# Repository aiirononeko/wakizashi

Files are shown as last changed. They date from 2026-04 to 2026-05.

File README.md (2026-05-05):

# Wakizashi

極限までミニマルな36キーBLE無線キーボード（revB）。メインキーボードとは別に、常に携えるサブキーボードとして設計。

- **キー数**: 36（3行×12列、論理 6×6 マトリクスに折り畳み）
- **配列**: オーソリニア（格子配列）
- **キーピッチ**: 16mm
- **接続**: BLE無線（USB-Cは充電とファーム書き込み用）
- **MCU**: XIAO nRF52840
- **キースイッチ**: Kailh Choc V2（ホットスワップ対応）
- **電源**: LiPoバッテリー（PicoBlade 1.25mm 2ピン）
- **電池監視**: VBAT 分圧 (R2 2.2MΩ + R3 1MΩ) → P0.31 (AIN7)、BLE HID Battery Service でホスト通知
- **ステータス LED**: SK6812MINI × 1（裏面右奥、SPIM3 駆動）。BLE 接続=青常時、ペアリング待機=青点滅、USB 接続=白、電池低下=赤、緊急=赤点滅、充電中=黄点滅、アイドル時は AO3401A PMOS で VDD ごと遮断
- **ファームウェア**: [RMK](https://github.com/HaoboGu/rmk)（Rust）
- **ケース**: revB ケース一式（topplate / side / spacer / bottomplate、3MF と STEP を収録）

## リポジトリ構成

```
wakizashi/
├── firmware/           RMK ファームウェア（nRF52840）
├── case/               ケース出力データ（3MF / STEP）
├── tools/web-flasher/  ブラウザから書き込む Web Flasher
├── build-guide/        組み立てガイド
└── docs/               運用ドキュメント
```

## ドキュメント

- [組み立てガイド](./build-guide/) — 必要部品 / 組み立て手順
- [ファームウェアの書き込み](./docs/flashing.md) — Web Flasher / UF2 / ローカルビルド
- [リリース運用](./docs/releasing.md) — タグ付け / CI / Pages デプロイ

## ファームウェアの書き込み (概要)

ブラウザから 1 クリックで書き込める [Web Flasher](https://e-sp9.github.io/wakizashi/) を公開している。USB-C でつなげば、自動でブートローダに入り最新ファームを書き込む。詳細と代替手順は [docs/flashing.md](./docs/flashing.md) を参照。

## キーマップ

詳細仕様は [firmware/keyboard.toml](./firmware/keyboard.toml) を参照。ホームロウモッドは廃止し、左右外側の Tab/Ctrl/Shift・BS/Enter/MO2 を直接キー化。コンボ（Q+W=Esc / F+V=Space / J+M=Space / Z+X=LGui / F+D=英数 / J+K=かな）と 3 レイヤー構成（base / lower / raise）。`MO(1)` を押しながら右上端（Backspace 位置）で `Minus` を入力できる。RMK そのものは [RMK ドキュメント](https://rmk.rs/main/docs/) を参照。

## ライセンス

MIT License — 詳細は [LICENSE](./LICENSE) を参照。

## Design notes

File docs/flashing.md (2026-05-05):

# ファームウェアの書き込み

書き込み方法は 3 通り。いずれも USB-C ケーブル (データ通信対応) での PC 接続が必要。

## 1. Web Flasher (推奨)

ブラウザだけで最新ファームを書き込める。Chrome / Edge / Opera の最新版に対応。

👉 **[https://e-sp9.github.io/wakizashi/](https://e-sp9.github.io/wakizashi/)**

1. 「最新ファームを取得」— GitHub Releases から最新 DFU パッケージを同一オリジンで読み込む
2. 「キーボードを選択して再起動」— WebHID でキーボードを選ぶと、Vial の `BootloaderJump` コマンドで自動的にブートローダへ再起動
3. 「シリアルポートを選んで書き込み」— WebSerial でブートローダの CDC ポートを選ぶと、Nordic Legacy DFU で書き込みが始まる

ブラウザと仕組みの詳細は [tools/web-flasher/](../tools/web-flasher/) のソースを参照。

## 2. UF2 ドラッグ & ドロップ

Web Flasher が使えない環境でのフォールバック。

1. キーボードのリセットボタンを素早く 2 回押してブートローダモードに入る (PC 上に `XIAO-SENSE` などの USB ドライブが出現)
2. [Releases](https://github.com/e-sp9/wakizashi/releases/latest) から `wakizashi.uf2` をダウンロード
3. ダウンロードした `.uf2` をドライブにコピー — 自動的に書き込まれて再起動する

## 3. ローカルビルドから書き込み

ファームを改造したとき用。

### 環境セットアップ

- Rust toolchain (`rust-toolchain.toml` で固定)
- [`cargo-make`](https://github.com/sagiegurari/cargo-make)
- `cargo-binutils`, [`cargo-hex-to-uf2`](https://github.com/haobogu/cargo-hex-to-uf2) (Makefile.toml の中でインストール / 呼び出し)
- 任意: `adafruit-nrfutil` (`pip install adafruit-nrfutil`)

### UF2 を生成してドラッグ & ドロップ

```sh
cd firmware
cargo make uf2
# 生成された firmware/wakizashi.uf2 を UF2 と同じ手順でドライブにコピー
```

### adafruit-nrfutil で CDC DFU 書き込み

```sh
cd firmware
cargo make hex
adafruit-nrfutil dfu genpkg --dev-type 0x0052 --application wakizashi.hex wakizashi-dfu.zip
# Linux/macOS 例。Windows は COMn を指定
adafruit-nrfutil dfu serial --package wakizashi-dfu.zip -p /dev/ttyACM0 -b 115200
```

## トラブルシュート

| 症状 | 対処 |
|---|---|
| PC に USB デバイスとして見えない | ケーブルがデータ通信対応か確認 (充電専用ケーブルでは不可) |
| ブートローダに入れない | XIAO 本体のリセットボタンを **素早く 2 回** 押す（revB は外付けリセットスイッチを撤廃、ケース開口から XIAO 内蔵ボタンを直接押す）。LED が流れるように点滅したらブートローダ |
| Web Flasher の「シリアルポート選択」ダイアログに候補が出ない | キーボードがブートローダモードになっていない。手動で 2 回リセット |
| 書き込み後にキーボードが動かない | 再びブートローダに入り、[過去のリリース](https://github.com/e-sp9/wakizashi/releases) の `wakizashi.uf2` で復旧できる |
| Web Flasher の書き込みが `START_DFU` で止まる | ブラウザをハードリロード → 別のケーブル / ポートで再試行 |

詳細なログを追うときは、Web Flasher を開いて DevTools → Console を見る。`[dfu]` プレフィックスで TX/RX バイトが出力される。

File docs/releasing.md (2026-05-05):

# リリース運用

Wakizashi のファームウェアリリースは `main` への `firmware/` 変更マージを起点に自動化されている。手動で操作が必要になるのはメジャー / マイナーバージョンを上げるときだけ。

## 自動化フロー

```
firmware/ の変更が main にマージ
    │
    ▼  .github/workflows/auto-tag.yml
直近の v* タグから patch を +1 して新しいタグを push
    │
    ▼  .github/workflows/firmware.yml  (on push tags: 'v*')
UF2 / HEX / DFU zip をビルドして GitHub Release を作成
    │
    ▼  .github/workflows/pages.yml  (on release: published)
最新ファームを Web Flasher に同梱して GitHub Pages を再デプロイ
```

`firmware/` に触れない変更 (`tools/`, `case/`, `docs/`, `README.md` 等) は auto-tag の対象外なので、何度マージしてもタグは増えない。

## 日常のリリース: 何もしない

`firmware/` を変更した PR を `main` にマージするだけでよい。上記のフローがすべて走り、数分後には最新ビルドが [Web Flasher](https://e-sp9.github.io/wakizashi/) と [Releases](https://github.com/e-sp9/wakizashi/releases/latest) の両方で配布される。

## メジャー / マイナーを上げる: 手動

セマンティックバージョニングの意図を明示するため、patch 以外のバンプは手動で切る。

```sh
# 例: 破壊的変更で v1.0.0 に上げる
git tag v1.0.0
git push origin v1.0.0
```

タグ push 後は `firmware.yml` と `pages.yml` が自動で走って Release と Pages が更新される。

### auto-tag より先に手動でタグを切ってしまった場合

auto-tag は「HEAD にすでにタグがあれば skip」する判定を入れてあるので、手動タグの後に `firmware/` 変更を含む push が来ても重ねてタグは切られない。

### auto-tag が先に patch を切ってしまった場合

タグは同一コミットに複数付けられる。意図より小さなバンプが先に切られた場合、そのまま意図したバンプのタグを重ねて切れば、新しい Release はそちらで公開される (Release 本体は最新タグに紐づく)。必要であれば古いタグ / Release を削除して整理する。

## 手動実行

Actions タブから各 workflow を `Run workflow` で個別に動かせる。

- **Auto-tag firmware release** — `bump` (patch/minor/major) を選んで手動タグ付けできる。
- **Build firmware** — `workflow_dispatch` でビルド単体 (Release 添付は v* タグ push 時のみ)。
- **Deploy web flasher** — ファームを更新せず Pages だけ再デプロイ。

## ワークフローの責任範囲

| Workflow | トリガ | 仕事 |
|---|---|---|
| `auto-tag.yml` | `push` to main (firmware/ 変更時) / 手動 | 次のタグを決めて push するだけ |
| `firmware.yml` | 全 push / PR / `v*` タグ / 手動 | ビルド + アーティファクト保存。タグ push 時は Release 添付 |
| `pages.yml` | `push` to main (tools/web-flasher/ 変更時) / `release: published` / 手動 | Web Flasher + 最新ファームを Pages にデプロイ |

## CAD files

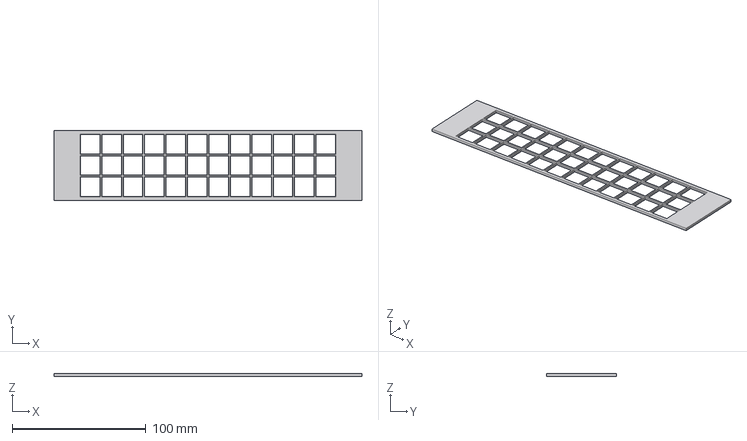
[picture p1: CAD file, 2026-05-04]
case/wakizashi_case.step
230.0 x 52.0 x 2.00 mm

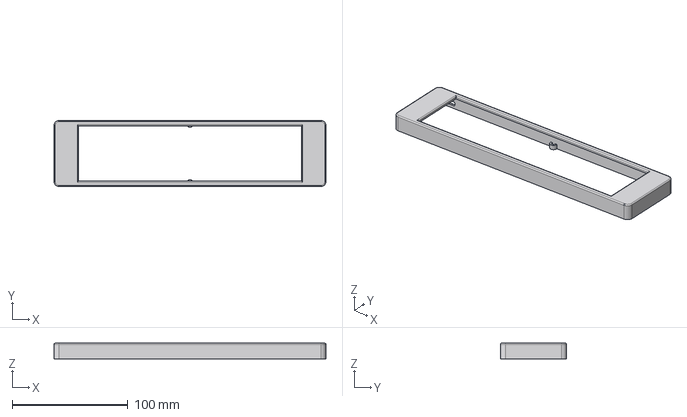
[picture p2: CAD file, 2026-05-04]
case/wakizashi_side.step
235.3 x 57.3 x 13.5 mm

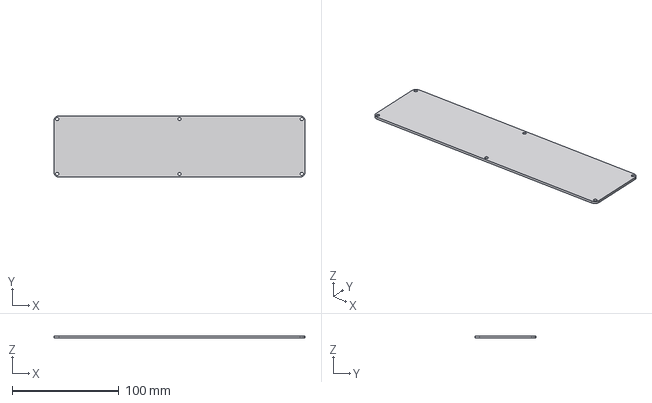
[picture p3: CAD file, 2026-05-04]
case/wakizashi_bottomplate.step
235.3 x 57.3 x 2.00 mm

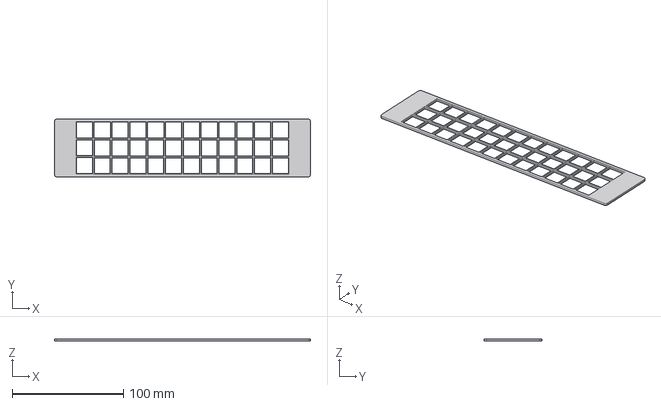
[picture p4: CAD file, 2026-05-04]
case/wakizashi_topplate.step
230.0 x 52.0 x 2.00 mm

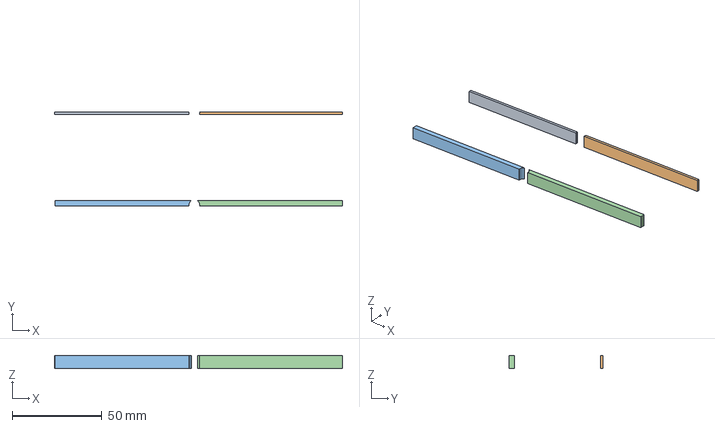
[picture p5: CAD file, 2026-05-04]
case/wakizashi_spacer.step
160.1 x 52.3 x 7.00 mm

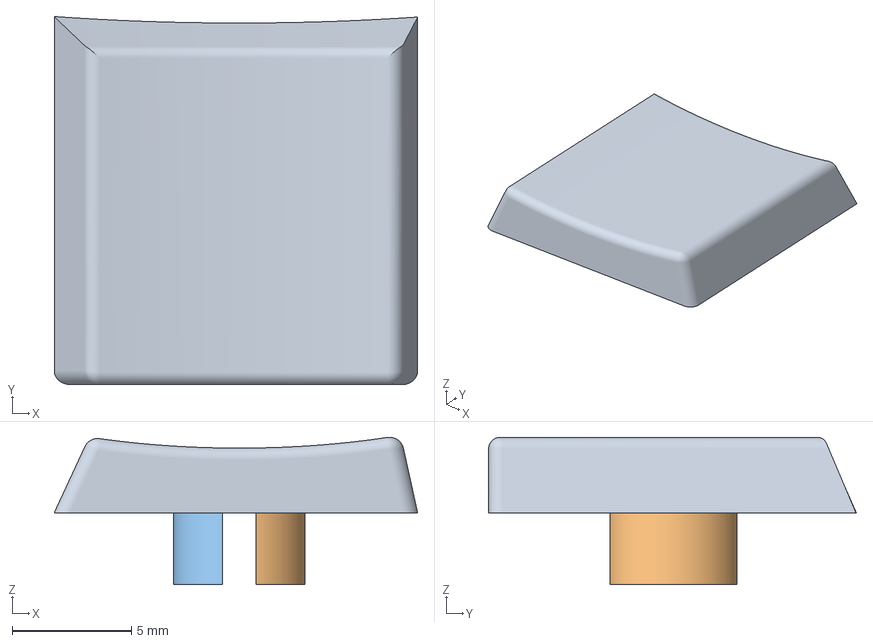
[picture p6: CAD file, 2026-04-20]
case/keycap_bottom.3mf
15.2 x 15.4 x 6.17 mm

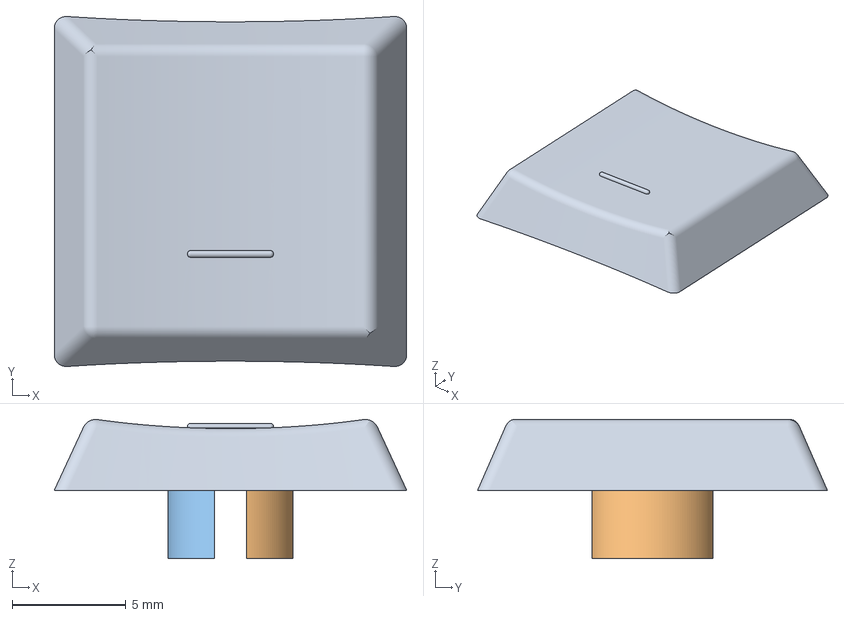
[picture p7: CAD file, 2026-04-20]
case/keycap_middle_dot.3mf
15.5 x 15.4 x 6.12 mm
keycap_middle_dot

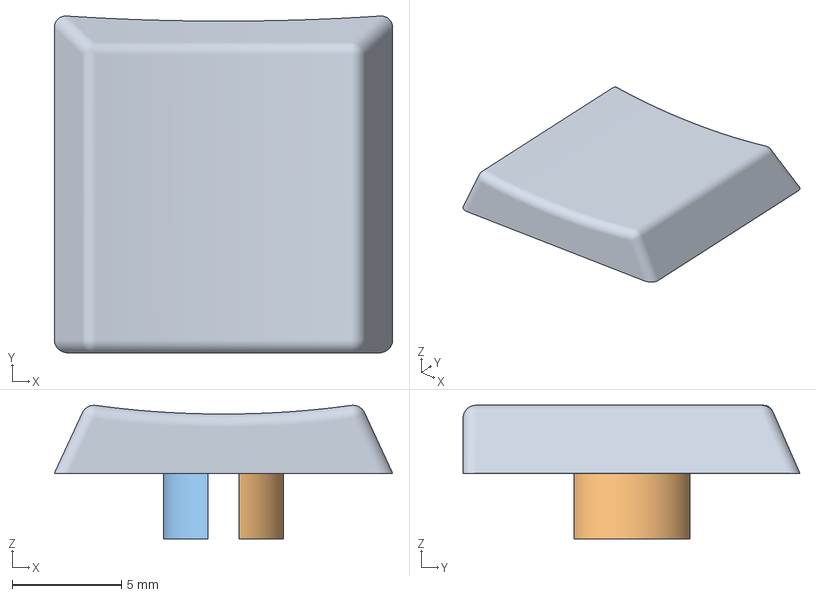
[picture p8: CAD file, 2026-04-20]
case/keycap_edge.3mf
15.5 x 15.5 x 6.12 mm
keycap_edge

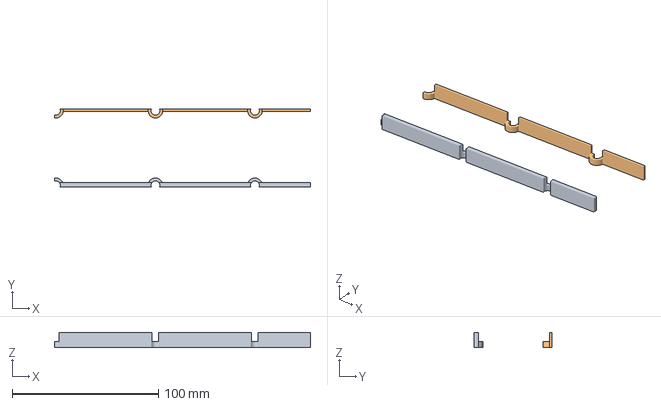
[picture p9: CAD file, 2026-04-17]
case/wakizashi_case_spacer.3mf
175.0 x 53.0 x 10.0 mm

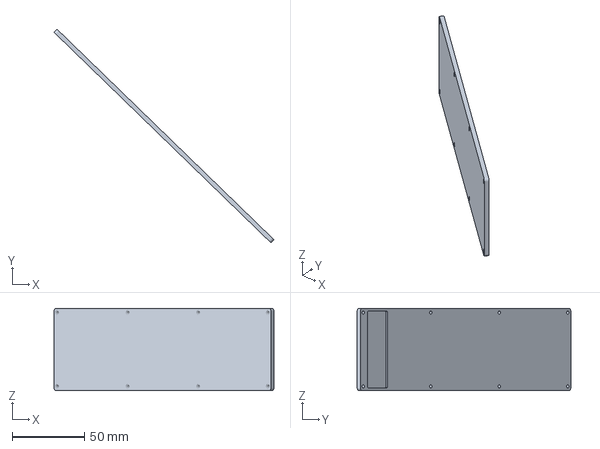
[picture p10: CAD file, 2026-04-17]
case/wakizashi_case_bottom.3mf
152.1 x 147.7 x 57.0 mm

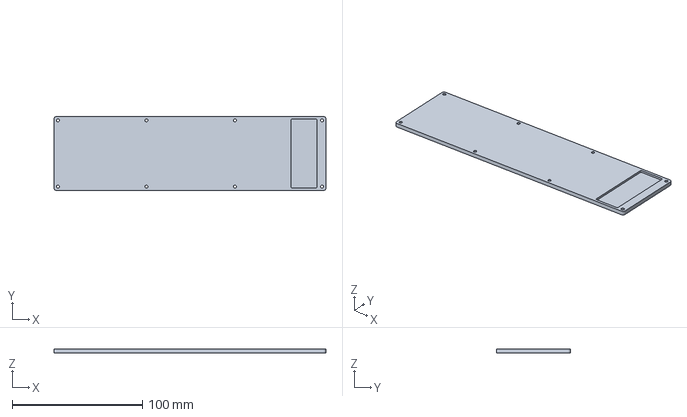
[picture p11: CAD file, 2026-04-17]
case/wakizashi_case_topplate.3mf
209.0 x 57.0 x 3.00 mm

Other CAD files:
case/keycap_middle.3mf
case/wakizashi_case.3mf
case/wakizashi_topplate.3mf

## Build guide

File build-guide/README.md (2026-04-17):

# Wakizashi ビルドガイド

（準備中）

## 目次（予定）

1. 必要な部品一覧（BOM）
2. 必要な工具
3. PCB 組み立て手順
   - ダイオード実装
   - MCU（XIAO nRF52840）実装
   - ホットスワップソケット実装
   - 電源回り（バッテリーコネクタ、スライドスイッチ、リセットボタン）
4. ケース組み立て手順
   - トッププレート
   - サイドケース
   - ボトムプレート
5. ファームウェア書き込み
6. キーキャップ・キースイッチの取り付け
7. 動作確認・トラブルシューティング

## 画像・図

組み立て過程の画像は `images/` ディレクトリに配置予定。

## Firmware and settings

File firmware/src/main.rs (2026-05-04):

#![no_main]
#![no_std]

use rmk::macros::rmk_keyboard;

#[rmk_keyboard]
mod keyboard {
    // PollingController トレイトはマクロ展開後の `status_led.polling_loop()` 呼び出しに
    // 必要なので、mod 直下の `use` でファイルスコープに上げる。Controller も同様。
    use rmk::controller::{Controller, PollingController};

    // SPIM3 の割り込みハンドラを RMK 生成の `bind_interrupts!(struct Irqs { ... })` に追加。
    // `add_interrupt!` は実マクロではなく rmk-macro が拾うシンボルで、トークンがそのまま
    // bind_interrupts! 構造体内に展開される。
    // 注: nRF52840 の SPIM3 ペリフェラル型は embassy-nrf では `SPI3` (`impl_spim!(SPI3, SPIM3, SPIM3)`)。
    // 割り込みベクタ名は SPIM3 のまま。
    add_interrupt! {
        SPIM3 => ::embassy_nrf::spim::InterruptHandler<::embassy_nrf::peripherals::SPI3>;
    }

    /// SK6812 ステータス LED + AO3401A PMOS ゲート制御コントローラ。
    /// `#[controller(poll)]` で RMK macro が `polling_loop()` を join_all_tasks に追加する。
    #[controller(poll)]
    fn status_led() {
        use embassy_nrf::gpio::{Level, Output, OutputDrive};
        use embassy_nrf::spim::{self, Spim};
        use embassy_time::{Duration, Instant, Timer};
        use rmk::ble::BleState;
        use rmk::channel::{ControllerSub, CONTROLLER_CHANNEL};
        use rmk::event::ControllerEvent;

        // SK6812 タイミング (revB SSOT §6.2):
        //   SPI 4 MHz、1 LED ビット = 4 SPI ビット (1µs/bit)
        //     0 → 0b1000 (T0H 250ns + T0L 750ns)
        //     1 → 0b1100 (T1H 500ns + T1L 500ns)
        //   1 LED あたり 24 LED ビット = 96 SPI ビット = 12 バイト
        const SK6812_BYTES: usize = 12;
        const IDLE_TIMEOUT: Duration = Duration::from_secs(20);
        const POLL_INTERVAL: Duration = Duration::from_millis(100);
        const BLINK_HALF_PERIOD_MS: u64 = 400;

        enum Pattern {
            Off,
            Solid(u8, u8, u8),
            Blink(u8, u8, u8),
        }

        struct StatusLed {
            spim: Spim<'static>,
            pmos: Output<'static>,
            sub: ControllerSub,
            ble_state: BleState,
            battery_level: Option<u8>,
            is_charging: bool,
            is_usb: bool,
            last_activity: Instant,
            led_powered: bool,
        }

        impl StatusLed {
            fn current_pattern(&self) -> Pattern {
                // 充電中は黄色点滅で識別
                if self.is_charging {
                    return Pattern::Blink(20, 12, 0);
                }
                // 電池警告は接続表示より優先
                if let Some(lvl) = self.battery_level {
                    if lvl <= 5 {
                        return Pattern::Blink(32, 0, 0); // 緊急: 赤点滅
                    }
                    if lvl <= 20 {
                        return Pattern::Solid(32, 0, 0); // 警告: 赤常時
                    }
                }
                // アイドル(警告と充電以外)は VDD ごと遮断
                if self.last_activity.elapsed() > IDLE_TIMEOUT {
                    return Pattern::Off;
                }
                // 通常表示
                if self.is_usb {
                    return Pattern::Solid(20, 20, 20); // 白 = USB 接続中
                }
                match self.ble_state {
                    BleState::Connected => Pattern::Solid(0, 0, 32), // 青常時 = BLE 接続中
                    BleState::Advertising => Pattern::Blink(0, 0, 32), // 青点滅 = ペアリング待機
                    BleState::None => Pattern::Off,
                }
            }

            async fn power_on(&mut self) {
                if !self.led_powered {
                    self.pmos.set_low(); // PMOS ON → LED VDD 通電
                    Timer::after(Duration::from_micros(500)).await; // VDD 安定待ち
                    self.led_powered = true;
                }
            }

            async fn power_off(&mut self) {
                if self.led_powered {
                    // 一旦黒を流して LED チップの状態をリセットしてから VDD カット
                    let buf = [0u8; SK6812_BYTES];
                    let _ = self.spim.write(&buf).await;
                    Timer::after(Duration::from_micros(100)).await;
                    self.pmos.set_high(); // PMOS OFF → LED VDD 遮断
                    self.led_powered = false;
                }
            }

            async fn write_color(&mut self, r: u8, g: u8, b: u8) {
                self.power_on().await;
                let mut buf = [0u8; SK6812_BYTES];
                encode_sk6812([g, r, b], &mut buf); // SK6812 ワイヤ順は GRB
                let _ = self.spim.write(&buf).await;
            }
        }

        impl Controller for StatusLed {
            type Event = ControllerEvent;

            async fn process_event(&mut self, event: Self::Event) {
                match event {
                    ControllerEvent::Battery(level) => self.battery_level = Some(level),
                    ControllerEvent::ChargingState(c) => self.is_charging = c,
                    ControllerEvent::BleState(_, s) => self.ble_state = s,
                    ControllerEvent::ConnectionType(t) => self.is_usb = t == 0,
                    ControllerEvent::Key(_, _) => self.last_activity = Instant::now(),
                    _ => {}
                }
            }

            async fn next_message(&mut self) -> Self::Event {
                self.sub.next_message_pure().await
            }
        }

        impl PollingController for StatusLed {
            const INTERVAL: Duration = POLL_INTERVAL;

            async fn update(&mut self) {
                let pattern = self.current_pattern();
                let blink_on = (Instant::now().as_millis() / BLINK_HALF_PERIOD_MS) % 2 == 0;
                match pattern {
                    Pattern::Off => self.power_off().await,
                    Pattern::Solid(r, g, b) => self.write_color(r, g, b).await,
                    Pattern::Blink(r, g, b) => {
                        if blink_on {
                            self.write_color(r, g, b).await;
                        } else {
                            self.write_color(0, 0, 0).await;
                        }
                    }
                }
            }
        }

        fn encode_sk6812(grb: [u8; 3], buf: &mut [u8; SK6812_BYTES]) {
            for b in buf.iter_mut() {
                *b = 0;
            }
            let mut byte_idx = 0usize;
            let mut high_nibble = true;
            for byte in grb {
                for i in (0..8).rev() {
                    let led_bit = (byte >> i) & 1;
                    let nibble: u8 = if led_bit == 1 { 0b1100 } else { 0b1000 };
                    if high_nibble {
                        buf[byte_idx] = nibble << 4;
                        high_nibble = false;
                    } else {
                        buf[byte_idx] |= nibble;
                        byte_idx += 1;
                        high_nibble = true;
                    }
                }
            }
        }

        // ----- 初期化 -----
        // SPIM3 を 4 MHz / MODE_0 / MSB-first で構成。SCK 不要 (1-wire LED) のため new_txonly_nosck。
        // Config は #[non_exhaustive] のため Default を経由して書き換える。
        let mut spim_config = spim::Config::default();
        spim_config.frequency = spim::Frequency::M4;
        spim_config.mode = spim::MODE_0;
        let spim = Spim::new_txonly_nosck(p.SPI3, Irqs, p.P1_15, spim_config);

        // PMOS ゲートは初期 HIGH (LED VDD 遮断)。アクティブ時のみ LOW にする。
        let pmos = Output::new(p.P0_30, Level::High, OutputDrive::Standard);

        let sub = ::defmt::unwrap!(CONTROLLER_CHANNEL.subscriber());

        StatusLed {
            spim,
            pmos,
            sub,
            ble_state: BleState::Advertising,
            battery_level: None,
            is_charging: false,
            is_usb: false,
            last_activity: Instant::now(),
            led_powered: false,
        }
    }
}

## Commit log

2026-04-15 Wakizashiファームウェア追加・SSOT/BOM/ケース仕様更新
    - RMKファームウェア一式追加（nRF52840 BLE、keyboard.toml設定）
    - キーマップをSSOTに同期: ホームロウモッド、コンボキー、BLEプロファイル切替
    - flash_nukeスクリプトの消去範囲をストレージ領域(0xA0000)まで拡大
    - SSOT更新: 配列確定、コンボ/HRM/Layer1仕様、ケース構成、改善事項
    - BOM更新: リセットスイッチ未実装を反映
    - ケース仕様書追加（トップ/ボトム/サイド）
2026-04-15 コンボキーのMT()キー対応: actionsにTapHold定義を指定
    RMK v0.8.2ではコンボのトリガー比較がKeyAction単位のため、
    MT()キーを含むコンボはSingle指定では一致しない。
    actions側にもMT()を指定することで正しくマッチするよう修正。
2026-04-17 サイドケースをリップ+スペーサー圧縮固定方式に変更、オフセット2.5mmへ縮小、キーマップ調整
2026-04-17 README・LICENSE(MIT)・build-guide スケルトンを追加
    頒布に向けた初期ドキュメント整備。詳細なビルド手順は build-guide/ に追って追加予定。
2026-04-17 英数・かな入力切り替えのコンボキーを実装
2026-04-17 ケースデータ追加
    [wakizashi_case.3mf, wakizashi_case_bottom.3mf, wakizashi_case_spacer.3mf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]
2026-04-18 ファームウェアビルドの GitHub Actions ワークフロー追加
2026-04-18 artifact 保持期間を 90日に延長
2026-04-18 cargo キャッシュキーにワークフローファイルを追加
    ツールインストール手順を変更した際にキャッシュが自動で無効化されるようにし、
    古い cargo-binutils / cargo-hex-to-uf2 バイナリが command -v ガードを
    すり抜けて使われないようにする。
2026-04-18 rustc スタック拡張で rmk-types コンパイル時の SIGSEGV を回避
    rmk-types 0.2.2 のマクロ展開で rustc のデフォルトスレッドスタック (8MB)
    を使い切り SIGSEGV するため、ジョブ全体で RUST_MIN_STACK=16MB を設定する。
    rustc 自身の help メッセージで推奨されている値。
2026-04-20 キーキャップの3Dデータを追加
    [keycap_bottom.3mf, keycap_edge.3mf, keycap_middle.3mf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]
2026-04-21 CI に DFU zip 生成と Release 添付を追加
    adafruit-nrfutil で `wakizashi-dfu.zip` を生成し、
    `v*` タグ push 時に UF2/HEX/ZIP を GitHub Release に
    添付する。Web 書き込みツールの配布経路となる。
2026-04-21 ブラウザからファームウェアを書き込む Web Flasher を追加
    Chromium 系ブラウザから WebHID + WebSerial で Wakizashi の
    ファームウェアを全自動書き込みできるようにする。これまで
    必要だったリセットボタンのダブルタップが不要になる。
    - `tools/web-flasher/`: 静的 HTML/JS
    - GitHub Releases から DFU zip を取得
    - WebHID で Vial `BootloaderJump (0x0B)` を送って soft-reset
    - WebSerial で Adafruit UF2 bootloader に Nordic Legacy DFU
    (SLIP + CRC16 + HciPacket) を話して書き込み
    - `.github/workflows/pages.yml`: main への push で GitHub Pages
    に自動デプロイ
    DFU 実装は adafruit-nrf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
2026-04-21 Pages workflow で未有効リポジトリでも自動有効化する
    `actions/configure-pages@v5` に `enablement: true` を指定し、
    Pages が未設定のリポジトリでも初回実行時に自動で Pages を
    有効化するようにする。
2026-04-21 Pages workflow の enablement 指定を削除
    `GITHUB_TOKEN` では Pages の初回有効化 API をコールする権限が
    なく、`enablement: true` では解決しない (Resource not accessible
    by integration)。Pages の初回有効化は Settings → Pages から
    手動で行う前提に戻す。
2026-04-21 Release 未作成時のエラーメッセージを明確にする
    Release が 1 件もない状態で最新取得を叩くと GitHub API が
    404 を返すだけで原因が分からないため、404 を検出して
    「初回リリースを作るには `git tag ...` してください」と
    具体的な手順を出すようにする。
2026-04-21 Release アセットを API エンドポイント経由で取得する
    `browser_download_url` は `objects.githubusercontent.com` への
    リダイレクトとなり、CORS 制約でブラウザからの fetch が失敗する
    ことがある。`api.github.com/.../releases/assets/{id}` に
    `Accept: application/octet-stream` を付けてリクエストすれば
    CORS 許可されたままバイナリを取得できる。
2026-04-21 ファームウェアを Pages 成果物に同梱する方式に切り替え
    GitHub Release のアセットは最終的に release-assets.githubusercontent.com
    へリダイレクトされ、そこでは `Access-Control-Allow-Origin` が返らず
    ブラウザからの fetch が常に CORS で拒否される。API 経由でも同じ
    リダイレクト先となるため回避できない。
    対策として、Pages デプロイ時に最新 Release の `wakizashi-dfu.zip` を
    `tools/web-flasher/firmware/` に同梱し、same-origin で fetch できる
    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
2026-04-21 DFU セッション開始時に DTR トグル + 初期バッファ排出
    adafruit-nrfutil は `DfuTransportSerial.open()` でポート確保直後に
    DTR を一度 Low → High する。これが bootloader 側の DFU state
    machine を初期化する信号となっており、省くと START_DFU の ACK が
    返ってこない。同じ手順を WebSerial 側でも実施する。
    併せて、bootloader が起動時に吐くバナーや残留バイトが ACK と
    混同されないよう、DTR トグル後に 150ms の受信ドレインを挟んで
    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
2026-04-21 Web Flasher に SVG favicon を追加
    favicon が未配置で 404 が出ていたので、キーキャップを模した
    シンプルな SVG favicon を置いて解消する。
2026-04-21 DFU セッションに診断ログと write タイムアウトを追加
    START_DFU で無応答のままハングする状況を切り分けるため、
    - 選択された USB VID/PID を表示
    - port.open, DTR トグル, ドレインそれぞれに完了ログ
    - 送信時は TX バイトの先頭 32B を 16 進で出力
    - writer.write() 自体に 3 秒タイムアウトを設けて、書き込みが
    そもそも OS レベルで止まっているのか、書けたけど ACK が
    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
2026-04-21 受信フレームの resolver 呼び出しを修正 + RX 生バイトログ
    SerialIO.readLoop が `resolver(f)` と呼んでいたが、pendingResolvers
    の要素は `{resolve, reject}` オブジェクトなので関数として呼べず、
    実際には readLoop の try/catch に TypeError が吸われて waiter が
    解決されないケースが存在した。`resolver.resolve(f)` に修正する。
    併せて、bootloader からの応答が一切来ていないのか、来ているが
    SLIP フレーム化できていないのかを可視化するため、受信生バイトを
    先頭 32B までログに出す。
2026-04-21 DFU の詳細バイトログは console.debug に逃がす
    動作確認が済んだので、バイト単位の TX/RX ログを UI ログから
    外し DevTools の console.debug 側にのみ残す。UI ログは
    START_DFU / INIT_PACKET / DATA / STOP_DATA 等の節目だけ出るため、
    ユーザが進捗を把握しやすくなる。
2026-04-21 main への firmware 変更で patch バージョンを自動タグ付け
    main ブランチに firmware/ 配下の変更が入るたびに、直近の v* タグ
    から patch を +1 して新しいタグを自動付与する。タグ push が
    firmware.yml を発火させるので、ビルド → Release 添付 →
    Pages 再デプロイまで自動で流れる。
    - `workflow_dispatch` で bump 種別 (patch/minor/major) を指定可能
    - HEAD が既にタグ付け済みの場合は無限ループ防止のため skip
    - `concurrency.cancel-in-progress: false` で連続 push でも全て
    順番に処理する
2026-04-21 運用ドキュメントを docs/ に集約
    README に雑多に書いていた書き込み手順と、これまで口頭 (チャット) で
    合意していたリリース運用ルールを docs/ に移して明文化する。
    - `docs/flashing.md`: Web Flasher / UF2 / ローカルビルド 3 通りと
    トラブルシュート。README にあった短い書き込み手順を吸収。
    - `docs/releasing.md`: main マージ → 自動タグ → Release → Pages
    デプロイのフロー。major/minor は手動で切る運用を明記。
    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
2026-05-04 Wakizashi-revB対応
    [wakizashi_bottomplate.step, wakizashi_case.step, wakizashi_side.step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]
2026-05-04 キーマップにBT操作と記号レイヤーを追加
2026-05-04 生成物のignoreを追加
2026-05-05 WebFlasherの公開URLを更新
